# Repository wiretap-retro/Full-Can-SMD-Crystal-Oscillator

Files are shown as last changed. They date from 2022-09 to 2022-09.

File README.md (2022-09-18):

# Full Can SMD Crystal Oscillator
A full can crystal oscillator replacement using 3.3V SMD components for 5V systems.

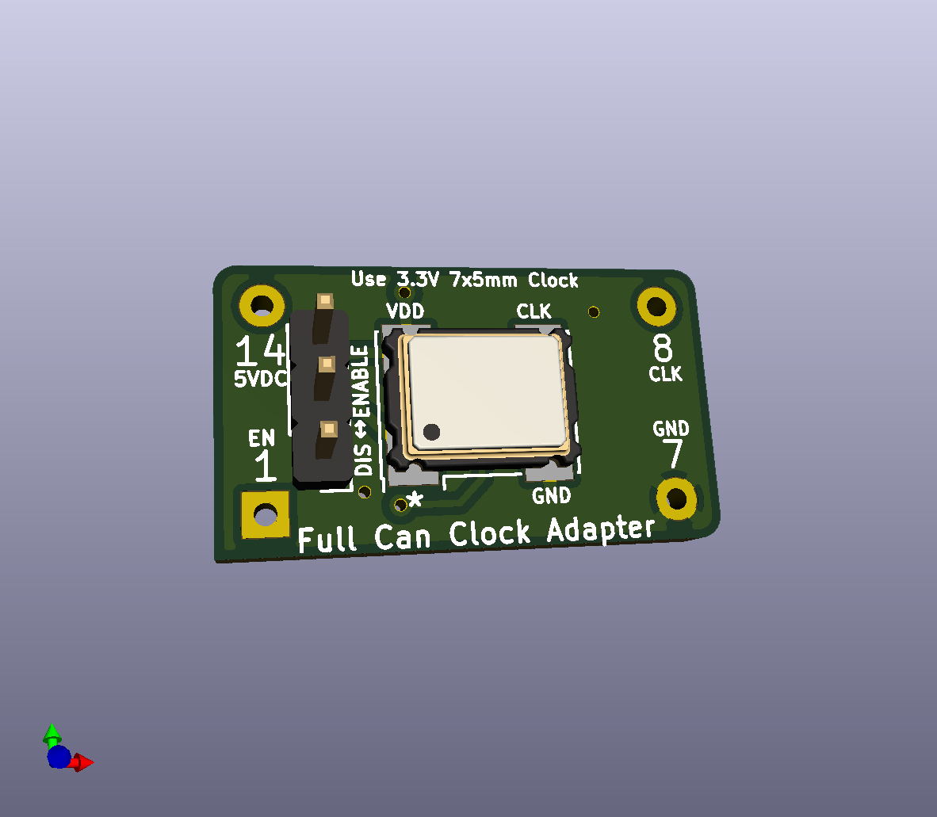
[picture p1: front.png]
front

\
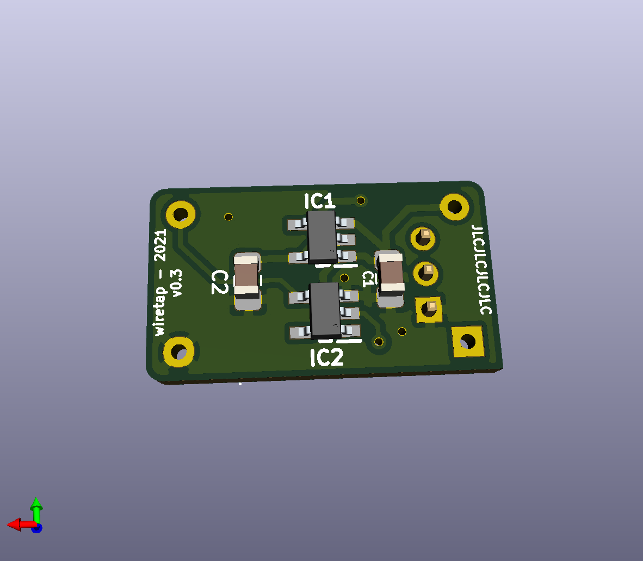
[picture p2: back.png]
back


## Info
This board is a full can crystal oscillator replacement for 5V systems. It uses 3.3v SMD components. It also features an enable/disable pin if your parent board requires it.

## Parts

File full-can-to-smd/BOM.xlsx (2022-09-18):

Reference | Value | Footprint | Description | Manufacturer_Name | Manufacturer_Part_Number | Mouser Part Number
X1 | your frequency | Oscillator:Oscillator_SMD_Abracon_ASV-4Pin_7.0x5.1mm | 3.3V Crystal Oscillator 7x5mm or 7x5.1mm | Various | Various | Various
C1, C2 | 1uF | Capacitor_SMD:C_0805_2012Metric_Pad1.15x1.40mm_HandSolder | 0805 1uF SMD Ceramic Capacitor | Kemet | C0805C105K4RAC7210 | 80-C0805C105K4R7210
IC2 | SN74LV1T34DBVRG4 | SOT95P280X145-5N | Single Power Supply BUFFER Logic Level Shifter (no enable) | Texas Instruments | SN74LV1T34DBVRG4 | 595-SN74LV1T34DBVRG4
IC1 | ADP1710AUJZ-3.3-R7 | SOT95P280X100-5N | LDO Voltage Regulators IC 150mA LDO CMOS | Linear Technology | ADP1710AUJZ-3.3-R7 | 584-ADP1710AUJZ3.3R7
J1 | DISABLE | PinHeader_2.00mm:PinHeader_1x03_P2.00mm_Vertical | 1x03 2.00mm Clock Disable Jumper | Amphenol | G8250031000YEU | 523-G8250031000YEU

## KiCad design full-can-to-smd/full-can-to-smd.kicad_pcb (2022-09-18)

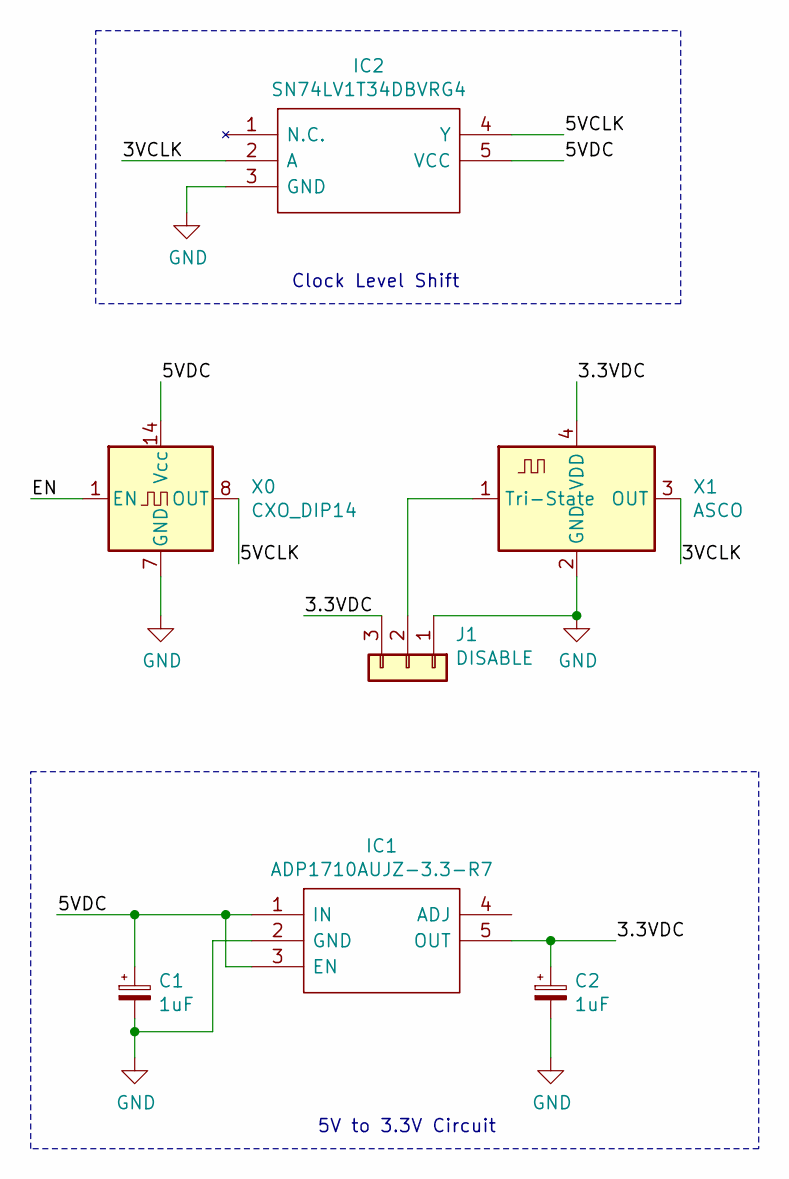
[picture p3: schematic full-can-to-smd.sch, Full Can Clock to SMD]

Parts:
C1, C2: 1uF; C_0805_2012Metric_Pad1.15x1.40mm_HandSolder
IC1: ADP1710AUJZ-3.3-R7; SOT95P280X100-5N; Mouser Part Number 584-ADP1710AUJZ3.3R7
IC2: SN74LV1T34DBVRG4; SOT95P280X145-5N; Mouser Part Number 595-SN74LV1T34DBVRG4
J1: DISABLE; PinHeader_1x03_P2.00mm_Vertical
X0: CXO_DIP14; Oscillator_DIP-14
X1: ASCO; Oscillator_SMD_Abracon_ASV-4Pin_7.0x5.1mm

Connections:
/3.3VDC: C2.1, IC1.5 (OUT), J1.3, X1.4 (VDD)
/3VCLK: IC2.2 (A), X1.3 (OUT)
/5VCLK: IC2.4 (Y), X0.8 (OUT)
/5VDC: C1.1, IC1.1 (IN), IC1.3 (EN), IC2.5 (VCC), X0.14 (Vcc)
/EN: X0.1 (EN)
GND: C1.2, C2.2, IC1.2 (GND), IC2.3 (GND), J1.1, X0.7 (GND), X1.2 (GND)
unnamed: J1.2, X1.1 (Tri-State)

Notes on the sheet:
5V to 3.3V Circuit
Clock Level Shift

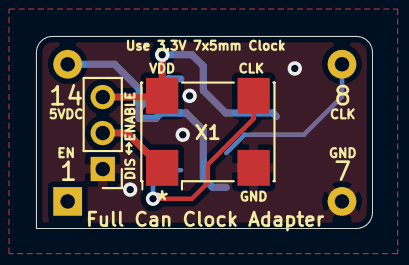
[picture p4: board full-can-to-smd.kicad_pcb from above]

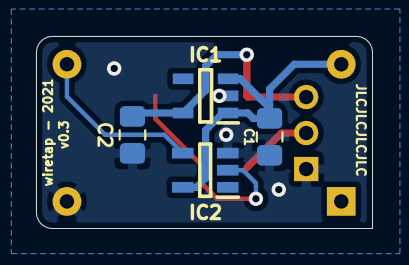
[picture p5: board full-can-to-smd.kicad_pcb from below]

Board: 2 copper layers, 18.7 x 10.7 mm, 7 parts (4 on the bottom side), 6 nets.
